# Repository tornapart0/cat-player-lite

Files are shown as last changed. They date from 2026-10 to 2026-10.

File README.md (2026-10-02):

Catmp3 diagram
The pipeline is a simple movement from the esp32  that goes simply into the speaker/audio jackl for headphones, and then i will create the buttons and knobs to do on board audio control for the mp3 player, I also need to design the website for the controller to upload and change music. 
Basically, 
0) purchase parts
1) recreate cad from enclosure and preview, also you can use the scad, I used codex to regenerate my blueprint, because I lost the file that I made on Shapr 3d.
2) obtain esp32 Xiao, and upload code using Arduino IDE
3) Solder the remaining parts ie speaker mic etc, whatever you ahve funding for to the ESP32 acording to wiring guide

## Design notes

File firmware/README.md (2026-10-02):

# Firmware setup

Install the current ESP32 Arduino board package, select **XIAO_ESP32C3**, and install:

- DFRobotDFPlayerMini;
- Adafruit GFX Library;
- Adafruit SSD1306;
- Adafruit MCP23017 Arduino Library.

Upload `cat_player_lite.ino` and open Serial Monitor at 115200 baud.

The code expects:

- SSD1306 address `0x3C`;
- MCP23017 address `0x20`;
- DFPlayer UART at 9600 baud;
- tracks named `/mp3/0001.mp3`, `/mp3/0002.mp3`, and so on.

The sketch is intentionally direct and small: the encoder changes volume, its push switch toggles play/pause, and the two face buttons select previous/next.

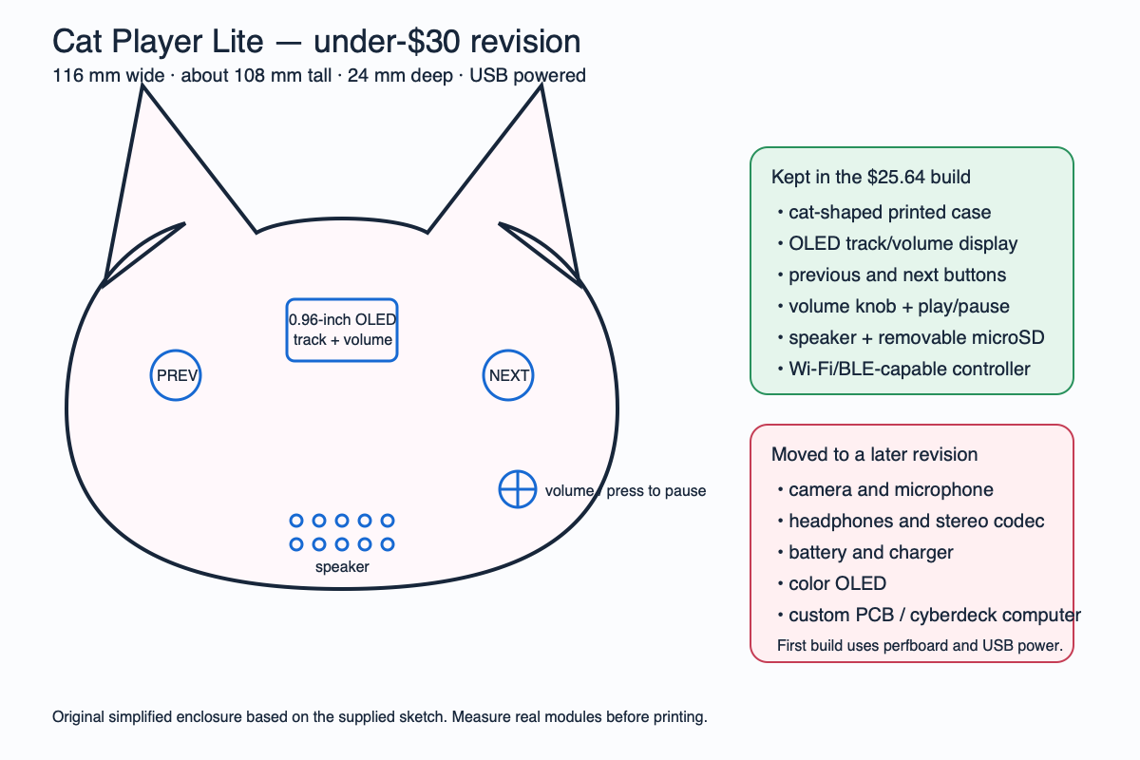
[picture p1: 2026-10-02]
enclosure/cat_player_lite_blueprint_preview.png

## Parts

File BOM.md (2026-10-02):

# Music macro Pad — bill of materials

<!-- Generated by Half Life from project cmuozfr7e02qe01s1m41wpw9z. Edits here are overwritten on the next sync. -->
<!-- Generated: 2026-10-02T02:02:31.462Z -->

> [!NOTE]
> This parts list is mirrored from [Half Life](https://halflife.hackclub.com). Editing it here will not change the platform's copy, and the next sync overwrites this file.

| Week | Tier | Parts funding |
| --- | --- | --- |
| Warm-up | Tier 1 | $30.00 |

| Part | What it's for | Qty | Unit | Total | Vendor |
| --- | --- | --- | --- | --- | --- |
| [Microcontroller](https://www.seeedstudio.com/Seeed-XIAO-ESP32C3-p-5431.html) | Official XIAO ESP32-C3 price checked 2026-10-01 | 1 | $4.99 | $4.99 | [Seeed Studio](https://www.seeedstudio.com/Seeed-XIAO-ESP32C3-p-5431.html) |
| [MP3 module](https://www.dfrobot.com/product-1121.html) | DFPlayer Mini DFR0299 | 1 | $5.90 | $5.90 | [DFRobot](https://www.dfrobot.com/product-1121.html) |
| [OLED](https://www.aliexpress.us/item/1005008516112334.html) | Choose a four-pin 0.96 inch 128x64 I2C SSD1306 module | 1 | $3.88 | $3.88 | [AliExpress marketplace](https://www.aliexpress.us/item/1005008516112334.html) |
| [I/O expander](https://www.adafruit.com/product/5346) | MCP23017 I2C breakout | 1 | $5.95 | $5.95 | [Adafruit](https://www.adafruit.com/product/5346) |
| [Speaker](https://www.adafruit.com/product/4227) | 8 ohm 1 watt mini oval speaker | 1 | $1.95 | $1.95 | [Adafruit](https://www.adafruit.com/product/4227) |
| [Rotary encoder](https://www.digikey.com/en/products/detail/bourns-inc/PEC11R-4315K-S0012/4699233) | Bourns encoder with push switch | 1 | $2.89 | $2.89 | [DigiKey](https://www.digikey.com/en/products/detail/bourns-inc/PEC11R-4315K-S0012/4699233) |
| [Momentary buttons](https://www.digikey.com/en/products/detail/omron-electronics-inc-emc-div/B3F-1000/33150) | Omron B3F-1000 normally-open tactile switches | 2 | $0.35 | $0.70 | [DigiKey](https://www.digikey.com/en/products/detail/omron-electronics-inc-emc-div/B3F-1000/33150) |
| microSD card | Use an existing FAT32 card preferably 32 GB or smaller | 1 | $0.01 | $0.01 | Reuse existing card |
| Prototype materials | Use existing perfboard wire headers solder and 1k resistor | 1 | $0.01 | $0.01 | Reuse home or school stock |
| Enclosure materials | Use existing filament and four small screws | 1 | $0.01 | $0.01 | Reuse school makerspace stock |
| **Parts subtotal** | — | — | — | **$26.29** | — |
| **Tax & shipping** | — | — | — | **$1.84** | — |
| **Total** | — | — | — | **$28.13** | — |

$1.87 left of the tier's funding.

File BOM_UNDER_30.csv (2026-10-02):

Qty | Part | What it's for | Unit Price USD | Vendor | Link | Required | Notes
1 | Microcontroller | Runs the controls display and player commands | 4.99 | Seeed Studio | https://www.seeedstudio.com/Seeed-XIAO-ESP32C3-p-5431.html | Yes | Official XIAO ESP32-C3 price checked 2026-10-01
1 | MP3 module | Reads the microSD card decodes MP3 files and drives the speaker | 5.90 | DFRobot | https://www.dfrobot.com/product-1121.html | Yes | DFPlayer Mini DFR0299
1 | OLED | Shows track title volume and playback status | 3.88 | AliExpress marketplace | https://www.aliexpress.us/item/1005008516112334.html | Yes | Choose a four-pin 0.96 inch 128x64 I2C SSD1306 module
1 | I/O expander | Provides enough clean inputs for the knob and buttons | 5.95 | Adafruit | https://www.adafruit.com/product/5346 | Yes | MCP23017 I2C breakout
1 | Speaker | Plays the DFPlayer audio output | 1.95 | Adafruit | https://www.adafruit.com/product/4227 | Yes | 8 ohm 1 watt mini oval speaker
1 | Rotary encoder | Controls volume and play or pause | 2.89 | DigiKey | https://www.digikey.com/en/products/detail/bourns-inc/PEC11R-4315K-S0012/4699233 | Yes | Bourns encoder with push switch
2 | Momentary buttons | Previous and next track controls | 0.35 | DigiKey | https://www.digikey.com/en/products/detail/omron-electronics-inc-emc-div/B3F-1000/33150 | Yes | Omron B3F-1000 normally-open tactile switches
1 | microSD card | Stores the MP3 music files | 0.01 | Reuse existing card |  | Yes | Use an existing FAT32 card preferably 32 GB or smaller
1 | Prototype materials | Connects and supports the electronic parts | 0.01 | Reuse home or school stock |  | Yes | Use existing perfboard wire headers solder and 1k resistor
1 | Enclosure materials | Prints and fastens the original cat-shaped case | 0.01 | Reuse school makerspace stock |  | Yes | Use existing filament and four small screws

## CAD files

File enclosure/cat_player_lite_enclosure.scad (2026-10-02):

// Cat Player Lite — compact, original enclosure for the under-$30 build.
// Units: millimetres. Measure the purchased modules before the full print.
// Set part to "front", "back", "assembly", or "fit_check".

part = "assembly";
$fn = 64;

head_width = 116;
head_height = 84;
ear_height = 22;
wall = 2.2;
front_depth = 8;
back_depth = 16;
fit_gap = 0.35;

screen_opening = [23, 13];
screen_center = [0, 8];
previous_center = [-35, 3];
next_center = [35, 3];
encoder_center = [37, -20];
screw_points = [[-39, 22], [39, 22], [-36, -26], [36, -26]];

module rounded_rectangle_2d(size, radius) {
    offset(r = radius)
        square([size[0] - 2 * radius, size[1] - 2 * radius], center = true);
}

module cat_outline_2d() {
    union() {
        scale([head_width / 2, head_height / 2]) circle(r = 1);
        polygon(points = [
            [-50, 23], [-42, 42 + ear_height], [-19, 34], [-15, 22]
        ]);
        polygon(points = [
            [50, 23], [42, 42 + ear_height], [19, 34], [15, 22]
        ]);
    }
}

module front_openings(depth) {
    translate([screen_center[0], screen_center[1], -1])
        linear_extrude(depth + 2) rounded_rectangle_2d(screen_opening, 1.5);

    for (p = [previous_center, next_center])
        translate([p[0], p[1], -1]) cylinder(d = 10.5, h = depth + 2);

    translate([encoder_center[0], encoder_center[1], -1])
        cylinder(d = 7.4, h = depth + 2);

    for (x = [-10 : 5 : 10])
        for (y = [-34 : 5 : -29])
            translate([x, y, -1]) cylinder(d = 2.5, h = depth + 2);
}

module screw_clearance(depth) {
    for (p = screw_points)
        translate([p[0], p[1], -1]) cylinder(d = 2.4, h = depth + 2);
}

module front_shell() {
    difference() {
        union() {
            difference() {
                linear_extrude(front_depth) cat_outline_2d();
                translate([0, 0, wall])
                    linear_extrude(front_depth - wall + 0.1)
                        offset(delta = -wall) cat_outline_2d();
            }
            for (p = screw_points)
                translate([p[0], p[1], wall]) cylinder(d = 7.2, h = front_depth - wall);
        }
        front_openings(front_depth);
        screw_clearance(front_depth);
    }
}

module back_shell() {
    difference() {
        union() {
            difference() {
                linear_extrude(back_depth) cat_outline_2d();
                translate([0, 0, wall])
                    linear_extrude(back_depth - wall + 0.1)
                        offset(delta = -wall) cat_outline_2d();
            }
            for (p = screw_points)
                translate([p[0], p[1], wall]) cylinder(d = 8, h = back_depth - wall - 1);
            translate([0, 0, back_depth - 1.9])
                linear_extrude(1.7)
                    difference() {
                        offset(delta = -wall - fit_gap) cat_outline_2d();
                        offset(delta = -wall - fit_gap - 1.3) cat_outline_2d();
                    }
        }

        // USB-C on the left side.
        translate([-head_width / 2, -5, back_depth * 0.55])
            cube([12, 11, 5], center = true);

        // DFPlayer microSD access at the bottom.
        translate([0, -head_height / 2, back_depth * 0.48])
            cube([19, 12, 4], center = true);

        for (p = screw_points)
            translate([p[0], p[1], back_depth - 10]) cylinder(d = 1.7, h = 12);
    }
}

module fit_check_coupon() {
    difference() {
        translate([0, 0, 1.1]) cube([94, 45, 2.2], center = true);
        translate([0, 8, -1])
            linear_extrude(5) rounded_rectangle_2d(screen_opening, 1.5);
        translate([-34, 5, -1]) cylinder(d = 10.5, h = 5);
        translate([34, 5, -1]) cylinder(d = 10.5, h = 5);
        translate([34, -14, -1]) cylinder(d = 7.4, h = 5);
    }
}

if (part == "front") {
    front_shell();
} else if (part == "back") {
    back_shell();
} else if (part == "fit_check") {
    fit_check_coupon();
} else {
    color([0.94, 0.57, 0.67, 0.78]) front_shell();
    color([0.32, 0.52, 0.74, 0.72])
        translate([0, 0, front_depth + back_depth + 5])
            mirror([0, 0, 1]) back_shell();
}

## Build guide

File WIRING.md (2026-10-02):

# Cat Player Lite wiring

## XIAO ESP32-C3 to DFPlayer Mini

| XIAO | DFPlayer | Purpose |
|---|---|---|
| `5V` | `VCC` | USB-derived power |
| `GND` | `GND` | Common ground |
| `D2 / GPIO4` | `RX` through 1 kΩ | Commands from XIAO |
| `D3 / GPIO5` | `TX` | Status back to XIAO |

The 1 kΩ series resistor on the DFPlayer RX connection is inexpensive insurance against noise and level-related instability.

## I2C bus

| XIAO | OLED | MCP23017 |
|---|---|---|
| `3V3` | `VCC` | `VCC` |
| `GND` | `GND` | `GND` |
| `D4 / GPIO6` | `SDA` | `SDA` |
| `D5 / GPIO7` | `SCL` | `SCL` |

Set the MCP23017 address pins `A0`, `A1`, and `A2` low for address `0x20`. Use only one set of I2C pull-ups; most breakout boards and OLED modules already include them.

## Controls on MCP23017

Every switch connects its input to ground when active. Firmware enables the pull-ups.

| MCP pin | Control |
|---|---|
| `GPA0` | Previous button |
| `GPA1` | Next button |
| `GPA2` | Encoder A |
| `GPA3` | Encoder B |
| `GPA4` | Encoder push switch — play/pause |

## Speaker

Connect the speaker only between DFPlayer `SPK1` and `SPK2`. Neither speaker lead goes to ground because this is a bridge-tied output.

Do not connect headphones to `SPK1`/`SPK2`. Headphones were removed from the budget revision.

## microSD layout

1. Format the card as FAT32.
2. Create a folder named `mp3` at the card root.
3. Name tracks `0001.mp3`, `0002.mp3`, and so on.
4. On macOS, remove `._` metadata files before ejecting the card; DFPlayer may mistake them for tracks.

## Assembly order

1. Test the DFPlayer, speaker, and microSD by themselves.
2. Add the XIAO UART connection and verify next/previous commands.
3. Add the OLED.
4. Add the MCP23017 and controls.
5. Transfer the working circuit to perfboard.
6. Print the enclosure fit-check section before the full case.

Stay on USB power for this revision. A battery and charger consume most of the remaining contingency and introduce a more serious safety requirement.

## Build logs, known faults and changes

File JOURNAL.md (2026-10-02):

# Music macro Pad — devlog

<!-- Generated by Half Life from project cmuozfr7e02qe01s1m41wpw9z. Edits here are overwritten on the next sync. -->
<!-- Generated: 2026-10-02T01:46:56.436Z -->

> [!NOTE]
> This devlog is mirrored from [Half Life](https://halflife.hackclub.com). Editing it here will not change the platform's copy, and the next sync overwrites this file.

> A cat-themed music player with knobs to control audio and a potential AI assistant.

| Week | Tier | Hours logged | Entries |
| --- | --- | --- | --- |
| Warm-up | Tier 1 | 6h | 2 |

## Contents

1. [2026-10-01 — I mapped out the parts list and drew a sketch](#2026-10-01-i-mapped-out-the-parts-list-and-drew-a-sketch)
2. [2026-10-01 — Revised plan to account for price limitations](#2026-10-01-revised-plan-to-account-for-price-limitations)

## Design

### 2026-10-01 — I mapped out the parts list and drew a sketch

**3h**

I mapped out the parts list and drew a sketch
The initial details are quite simple; the only challenge is building the PCB and the enclosure, as well as deciding which computer to use if I want to make it more of a portable cyberdeck than an audio player.



Created a workflow chart to plan

Blank diagram

Blueprint of case
Screenshot 2026-09-30 at 11.59.25 PM

Also, I want to add an mp3 card reader to play music from!

CAD files so far

Screenshot 2026-10-01 at 12.00.00 AM

Screenshot 2026-10-01 at 12.00.12 AM

### 2026-10-01 — Revised plan to account for price limitations

**3h**

Revised plan to account for price limitations

Screenshot 2026-10-01 at 9.23.05 PM

Tried to figure out setting up a github repo

Screenshot 2026-10-01 at 9.44.13 PM

Wrote the code, in C++ for esp32

Today's wprk was a lot of me attempting to figure out how github works, as typically i do not work with collaborators, and simply use random opensource airdrop alternatives across my own devices, it is interesting to see github.

I am essentially ready to purchase parts today.

Screenshot 2026-10-01 at 9.46.33 PM
as per this list, I have to add it to my project though.

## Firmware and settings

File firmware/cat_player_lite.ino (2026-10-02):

#include <Arduino.h>
#include <Wire.h>
#include <Adafruit_GFX.h>
#include <Adafruit_MCP23X17.h>
#include <Adafruit_SSD1306.h>
#include <DFRobotDFPlayerMini.h>

namespace Pins {
constexpr uint8_t dfPlayerRx = 5;  // XIAO D3 receives from DFPlayer TX.
constexpr uint8_t dfPlayerTx = 4;  // XIAO D2 sends through 1 kOhm to DFPlayer RX.
constexpr uint8_t i2cSda = 6;      // XIAO D4.
constexpr uint8_t i2cScl = 7;      // XIAO D5.
}  // namespace Pins

namespace Controls {
constexpr uint8_t previous = 0;
constexpr uint8_t next = 1;
constexpr uint8_t encoderA = 2;
constexpr uint8_t encoderB = 3;
constexpr uint8_t encoderPress = 4;
}  // namespace Controls

constexpr uint8_t oledAddress = 0x3C;
constexpr uint8_t mcpAddress = 0x20;
constexpr uint8_t screenWidth = 128;
constexpr uint8_t screenHeight = 64;

HardwareSerial dfSerial(1);
DFRobotDFPlayerMini player;
Adafruit_MCP23X17 controls;
Adafruit_SSD1306 display(screenWidth, screenHeight, &Wire, -1);

bool playerReady = false;
bool controlsReady = false;
bool displayReady = false;
bool paused = false;
int volumeLevel = 15;  // DFPlayer range: 0 to 30.
int currentTrack = 1;
int trackCount = 0;
uint8_t lastEncoderState = 0b11;
uint32_t lastInputScanMs = 0;

bool pressed(uint8_t pin) {
  return controls.digitalRead(pin) == LOW;
}

void drawScreen(const char* eventText) {
  if (!displayReady) return;

  display.clearDisplay();
  display.setTextColor(SSD1306_WHITE);
  display.setTextSize(1);
  display.setCursor(0, 0);
  display.println("CAT PLAYER LITE");
  display.drawLine(0, 10, 127, 10, SSD1306_WHITE);

  display.setCursor(0, 17);
  if (!playerReady) {
    display.println("PLAYER NOT FOUND");
  } else {
    display.printf("TRACK %04d", currentTrack);
    if (trackCount > 0) {
      display.printf(" / %d", trackCount);
    }
    display.println();
    display.printf("VOLUME %d / 30\n", volumeLevel);
    display.println(paused ? "PAUSED" : "PLAYING");
  }

  display.setCursor(0, 54);
  display.print(eventText);
  display.display();
}

void selectPreviousTrack() {
  if (!playerReady) return;
  player.previous();
  currentTrack = max(1, currentTrack - 1);
  paused = false;
  drawScreen("PREVIOUS");
}

void selectNextTrack() {
  if (!playerReady) return;
  player.next();
  currentTrack = trackCount > 0 ? min(trackCount, currentTrack + 1) : currentTrack + 1;
  paused = false;
  drawScreen("NEXT");
}

void togglePause() {
  if (!playerReady) return;
  paused = !paused;
  if (paused) {
    player.pause();
  } else {
    player.start();
  }
  drawScreen(paused ? "PAUSE" : "PLAY");
}

void scanControls() {
  static bool lastPrevious = false;
  static bool lastNext = false;
  static bool lastPress = false;
  static int8_t encoderAccumulator = 0;
  static const int8_t transitionDelta[16] = {
      0, -1, 1, 0,
      1, 0, 0, -1,
      -1, 0, 0, 1,
      0, 1, -1, 0};

  const bool nowPrevious = pressed(Controls::previous);
  const bool nowNext = pressed(Controls::next);
  const bool nowPress = pressed(Controls::encoderPress);

  if (nowPrevious && !lastPrevious) selectPreviousTrack();
  if (nowNext && !lastNext) selectNextTrack();
  if (nowPress && !lastPress) togglePause();

  lastPrevious = nowPrevious;
  lastNext = nowNext;
  lastPress = nowPress;

  const uint8_t encoderState =
      (controls.digitalRead(Controls::encoderA) << 1) |
      controls.digitalRead(Controls::encoderB);
  const uint8_t transition = (lastEncoderState << 2) | encoderState;
  encoderAccumulator += transitionDelta[transition];
  lastEncoderState = encoderState;

  if (encoderAccumulator >= 4 || encoderAccumulator <= -4) {
    const int8_t detent = encoderAccumulator > 0 ? 1 : -1;
    encoderAccumulator = 0;
    volumeLevel = constrain(volumeLevel + detent, 0, 30);
    if (playerReady) {
      player.volume(volumeLevel);
    }
    drawScreen(detent > 0 ? "VOLUME UP" : "VOLUME DOWN");
  }
}

void setup() {
  Serial.begin(115200);
  delay(500);

  Wire.begin(Pins::i2cSda, Pins::i2cScl);
  displayReady = display.begin(SSD1306_SWITCHCAPVCC, oledAddress);
  if (!displayReady) {
    Serial.println("OLED not found");
  }

  controlsReady = controls.begin_I2C(mcpAddress, &Wire);
  if (controlsReady) {
    for (uint8_t pin = Controls::previous; pin <= Controls::encoderPress; ++pin) {
      controls.pinMode(pin, INPUT_PULLUP);
    }
    lastEncoderState =
        (controls.digitalRead(Controls::encoderA) << 1) |
        controls.digitalRead(Controls::encoderB);
  }

  dfSerial.begin(9600, SERIAL_8N1, Pins::dfPlayerRx, Pins::dfPlayerTx);
  playerReady = player.begin(dfSerial, true, true);
  if (playerReady) {
    player.volume(volumeLevel);
    trackCount = player.readFileCounts();
    player.playMp3Folder(currentTrack);
  }

  if (displayReady) {
    drawScreen(playerReady ? "READY" : "CHECK PLAYER");
  }

  Serial.printf("DFPlayer: %s\n", playerReady ? "OK" : "not found");
  Serial.printf("Controls: %s\n", controlsReady ? "OK" : "not found");
  Serial.printf("Tracks: %d\n", trackCount);
}

void loop() {
  if (controlsReady && millis() - lastInputScanMs >= 5) {
    lastInputScanMs = millis();
    scanControls();
  }

  if (playerReady && player.available()) {
    const uint8_t eventType = player.readType();
    const int eventValue = player.read();
    Serial.printf("DFPlayer event %u value %d\n", eventType, eventValue);

    if (eventType == DFPlayerPlayFinished && !paused) {
      selectNextTrack();
    }
  }
}

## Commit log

2026-10-02 Add under-$30 bill of materials
    Added a BOM (Bill of Materials) for components under $30.
    [BOM_UNDER_30.csv]
2026-10-02 Add wiring and assembly guide
    Document wiring instructions for Cat Player Lite including connections for XIAO ESP32-C3, DFPlayer Mini, I2C bus, controls, speaker setup, microSD layout, and assembly order.
2026-10-02 Add ESP32 player firmware
2026-10-02 Add enclosure CAD and blueprint files
    [cat_player_lite_enclosure.scad]
2026-10-02 Add checked vendor links and prices
    Update the Half-Life BOM source with current product links, unit prices, and reuse assumptions while keeping the build under $30.
    [BOM_UNDER_30.csv]
2026-10-21 Expand project documentation and add validated enclosure STEP models
2026-10-21 Replace unavailable BOM parts and move to Tier 2 budget
2026-10-21 Revise README with updates and clarifications
    Updated project description and firmware setup instructions. Clarified wiring plan and enclosure details.
